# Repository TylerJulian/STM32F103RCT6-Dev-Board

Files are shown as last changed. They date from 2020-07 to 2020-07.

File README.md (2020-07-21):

# STM32F103RCT6 Developement board

A stm32f103RCT6 Breakout board for Sooner Competitive Robotics and Personal use.

Contains PORTs for CAN-Bus protocol and a 6 pin molex power and signal connection.

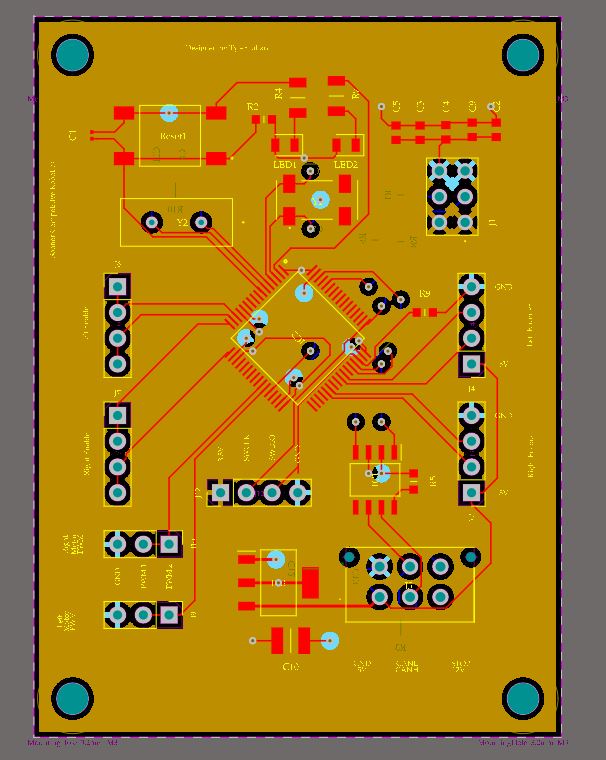
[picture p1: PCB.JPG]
Image of PCB


## Major Components

1x [STM32f103RCT6 microcontroller](https://www.mouser.com/ProductDetail/STMicroelectronics/STM32F103RCT6?qs=%252BB84zevwoRA6TYzZIgOIoA%3D%3D)

1x [SN65HVD230QDR CAN transceiver](https://www.mouser.com/ProductDetail/Texas-Instruments/SN65HVD230QDR?qs=QViXGNcIEAvSeznLG41lqg%3D%3D)

1x [Molex Connector](https://www.molex.com/molex/products/part-detail/pcb_headers/0430450612)

## Minor Components

See bill of materials

## Designers

- Tyler Julian - Designer - [TylerJulian](https://github.com/tylerjulian)

## Built With

- Kicad and Altium- Schematic designed in Kicad then imported to Altium  

## Errata
* tbd

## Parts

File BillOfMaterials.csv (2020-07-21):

Reference | Quantity | Value | Footprint | Datasheet | Description | Height | Manufacturer_Name | Manufacturer_Part_Number | Mouser Part Number | Mouser Price/Stock
C1 | 1 | 1uF | CAPC0603X33N | https://psearch.en.murata.com/capacitor/product/GRM033R61A105ME15%23.html | Capacitor GRM03_0.09 L=0.6mm W=0.3mm T=0.3mm | 0.33 | Murata Electronics | GRM033R61A105ME15J | 81-GRM033R61A105ME5J | https://www.mouser.co.uk/ProductDetail/Murata-Electronics/GRM033R61A105ME15J?qs=5aG0NVq1C4ydTrRWdKcXxA%3D%3D
C10 | 1 | 330uF | CAPC3225X270N | http://psearch.en.murata.com/capacitor/product/GRM32ER71E226KE15%23.pdf | MURATA - GRM32ER60G337ME05K - CAP, MLCC, X5R, 330UF, 4V, 1210 | 2.7 | Murata Electronics | GRM32ER60G337ME05K | 81-GRM32ER60G337ME5K | https://www.mouser.co.uk/ProductDetail/Murata-Electronics/GRM32ER60G337ME05K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
C11 C8 | 2 | 20pf | CAPC0603X33N | https://componentsearchengine.com/Datasheets/1/GRM0335C1H200JA01D.pdf | Multilayer Ceramic Capacitors MLCC - SMD/SMT 0201 20pF 50volts C0G +/-5% | 0.33 | Murata Electronics | GRM0335C1H200JA01D | 81-GRM0335C1H200JA1D | https://www.mouser.com/Search/Refine.aspx?Keyword=81-GRM0335C1H200JA1D
C12 | 1 | 100uF | CAPC3216X180N | https://psearch.en.murata.com/capacitor/product/GRM31CR61A107ME05%23.html | Multilayer Ceramic Capacitors MLCC - SMD/SMT 100UF 10V 20% 1206 | 1.8 | Murata Electronics | GRM31CR61A107ME05L | 81-GRM31CR61A107ME5L | https://www.mouser.co.uk/ProductDetail/Murata-Electronics/GRM31CR61A107ME05L?qs=chTDxNqvsylSo93CzdbYkQ%3D%3D
C2 C3 C4 C5 C13 C9 | 6 | 100nf | CAPC1608X100N | https://psearch.en.murata.com/capacitor/product/GCJ188L8EL104KA07%23.html | Multilayer Ceramic Capacitors MLCC - SMD/SMT | 1 | Murata Electronics | GCJ188L8EL104KA07D | 81-GCJ188L8EL104KA7D | https://www.mouser.co.uk/ProductDetail/Murata-Electronics/GCJ188L8EL104KA07D?qs=rrS6PyfT74fTpbPMbkPm2A%3D%3D
C6 C7 | 2 | 8PF | CAPC0603X33N | https://componentsearchengine.com/Datasheets/1/GRM0335C1E8R0CA01D.pdf | Multilayer Ceramic Capacitors MLCC - SMD/SMT 0201 8.0pF 25volts C0G +/-0.25pF | 0.33 | Murata Electronics | GRM0335C1E8R0CA01D | 81-GRM0335C1E8R0CA1D | https://www.mouser.com/Search/Refine.aspx?Keyword=81-GRM0335C1E8R0CA1D
IC1 | 1 | SN65HVD230QDR | SOIC127P600X175-8N | http://www.ti.com/lit/gpn/SN65HVD230Q | 3.3-V CAN Transceiver with Standby Mode | 1.75 | Texas Instruments | SN65HVD230QDR | 595-SN65HVD230QDR | https://www.mouser.co.uk/ProductDetail/Texas-Instruments/SN65HVD230QDR?qs=QViXGNcIEAvSeznLG41lqg%3D%3D
IC2 | 1 | STM32F103RCT6 | QFP50P1200X1200X160-64N | http://www.st.com/st-web-ui/static/active/en/resource/technical/document/datasheet/CD00191185.pdf | STM32F103RCT6, 32 bit ARM Cortex M3 Microcontroller 72MHz 256 kB Flash, 48 kB RAM, USB CAN I2C 64-Pin LQFP | 1.6 | STMicroelectronics | STM32F103RCT6 | 511-STM32F103RCT6 | https://www.mouser.co.uk/ProductDetail/STMicroelectronics/STM32F103RCT6?qs=%252BB84zevwoRA6TYzZIgOIoA%3D%3D
IC3 | 1 | REG1117-3.3 | SOT230P700X180-4N | http://www.ti.com/lit/ds/symlink/reg1117-33.pdf | 800mA,3.3V,LDO Voltage Reg.,REG1117-3.3 Texas Instruments REG1117-3.3, LDO Voltage Regulator, 0.8A, 3.3 V +/-1%, 3.8 15 Vin, 4-Pin SOT-223 | 1.8 | Texas Instruments | REG1117-3.3 | 595-REG1117-3.3 | https://www.mouser.co.uk/ProductDetail/Texas-Instruments/REG1117-33?qs=sSOk4GDDv7y9bL0tER%2FZXw%3D%3D
J1 | 1 | Boot Pins | TSW-103-XX-YY-D | http://suddendocs.samtec.com/prints/tsw-xxx-xx-xxx-x-xx-xxx-mkt.pdf | 6 Position, Classic PCB Header Strips, 0.100&quot; pitch |  | SAMTEC | TSW-103-07-T-D | 200-TSW10307TD | https://www.mouser.co.uk/ProductDetail/Samtec/TSW-103-07-T-D?qs=hzq9O0YpnZtW9OBlDqG3zw%3D%3D
J10 | 1 | Left Motor PWM | Connector_PinHeader_2.54mm:PinHeader_1x03_P2.54mm_Vertical | ~
J11 | 1 | Power Input | TerminalBlock:TerminalBlock_Altech_AK300-2_P5.00mm | ~
J12 | 1 | SWD | Connector_PinHeader_2.54mm:PinHeader_1x04_P2.54mm_Vertical | ~
J2 | 1 | CAN terminal | TerminalBlock:TerminalBlock_Altech_AK300-2_P5.00mm | ~
J3 | 1 | Righ Encoder | Connector_PinHeader_2.54mm:PinHeader_1x04_P2.54mm_Vertical | ~
J4 | 1 | Left Encoder | Connector_PinHeader_2.54mm:PinHeader_1x04_P2.54mm_Vertical | ~
J5 | 1 | CAN Molex | 430450612 | http://www.molex.com/webdocs/datasheets/pdf/en-us/0430450612_PCB_HEADERS.pdf | 6 way 2 row vertical header,3mm pitch Molex MICRO-FIT 3.0 Series, Series Number 43045, 3mm Pitch 6 Way 2 Row Straight PCB Header, Solder Termination, 5A | 9.91 | Molex | 43045-0612 | 538-43045-0612 | https://www.mouser.co.uk/ProductDetail/Molex/43045-0612?qs=KC2ywxza1kqWo9LLJ5Lh3w%3D%3D
J6 | 1 | Left Enable | Connector_PinHeader_2.54mm:PinHeader_1x04_P2.54mm_Vertical | ~
J7 | 1 | Right Enable | Connector_PinHeader_2.54mm:PinHeader_1x04_P2.54mm_Vertical | ~
J8 J13 | 2 | GPIO Pins | Connector_PinHeader_2.54mm:PinHeader_2x13_P2.54mm_Vertical | ~
J9 | 1 | Right Motor PWM | Connector_PinHeader_2.54mm:PinHeader_1x03_P2.54mm_Vertical | ~
LED1 | 1 | Power Indicator LED | LEDC2012X90N | https://componentsearchengine.com/Datasheets/1/LH R974-LP-1.pdf | Standard LEDs - SMD Hyper Red, 645nm 41mcd, 20mA | 0.9 | OSRAM | LH R974-LP-1 | 720-LHR974-LP-1 | https://www.mouser.co.uk/ProductDetail/OSRAM-Opto-Semiconductors/LH-R974-LP-1?qs=LsPilcdHE7GU7OJxbROzng%3D%3D
LED2 | 1 | LG_R971-KN-1 | LEDC2012X80N |  | Standard LEDs - SMD Green, 570nm 26mcd, 20mA | 0.8 | OSRAM | LG R971-KN-1 | 720-LGR971-KN-1 | https://www.mouser.co.uk/ProductDetail/OSRAM-Opto-Semiconductors/LG-R971-KN-1?qs=LsPilcdHE7EX1EB7GCLHxg%3D%3D
R1 R6 | 2 | 100k | RESC1608X55N |  | Thick Film Resistors - SMD 1/10Watt 100Kohms 1% Commercial Use | 0.55 | Vishay | CRCW0603100KFKEAC | 71-CRCW0603100KFKEAC | https://www.mouser.co.uk/ProductDetail/Vishay-Dale/CRCW0603100KFKEAC?qs=E3Y5ESvWgWPxzfNYyMgX1w%3D%3D
R10 | 1 | 1M | RESC3216X60N | https://componentsearchengine.com/Datasheets/1/CRCW12061M00FKEAC.pdf | Thick Film Resistors - SMD 1/4Watt 1Mohms 1% Commercial Use | 0.6 | Vishay | CRCW12061M00FKEAC | 71-CRCW12061M00FKEAC | https://www.mouser.com/Search/Refine.aspx?Keyword=71-CRCW12061M00FKEAC
R2 R5 R9 R8 | 4 | 10k | RESC1608X55N | https://componentsearchengine.com/Datasheets/1/CRCW060310K0FKEAC.pdf | Thick Film Resistors - SMD 1/10Watt 10Kohms 1% Commercial Use | 0.55 | Vishay | CRCW060310K0FKEAC | 71-CRCW060310K0FKEAC | https://www.mouser.co.uk/ProductDetail/Vishay-Dale/CRCW060310K0FKEAC?qs=E3Y5ESvWgWPkZNxkE0GwZg%3D%3D
R3 | 1 | 120 | RESC3216X60N | http://componentsearchengine.com/Datasheets/1/CRCW1206120RFKEAC.pdf | Thick Film Resistors - SMD 1/4Watt 120ohms 1% Commercial Use | 0.6 | Vishay | CRCW1206120RFKEAC | 71-CRCW1206120RFKEAC | https://www.mouser.co.uk/ProductDetail/Vishay-Dale/CRCW1206120RFKEAC?qs=E3Y5ESvWgWNzKkdgimZfBg%3D%3D
R4 R7 | 2 | 510 | RESC3216X60N | https://componentsearchengine.com/Datasheets/1/CRCW1206510RFKEAC.pdf | Thick Film Resistors - SMD 1/4Watt 510ohms 1% Commercial Use | 0.6 | Vishay | CRCW1206510RFKEAC | 71-CRCW1206510RFKEAC | https://www.mouser.com/Search/Refine.aspx?Keyword=71-CRCW1206510RFKEAC
Reset1 | 1 | Reset | LL3301NF065QG | http://spec_sheets.e-switch.com/specs/P090002.pdf | E-SWITCH - LL3301NF065QG - TACTILE SW, SPST, 0.05A, 12VDC, SOLDER | 4 | E-Switch | LL3301NF065QG | 612-LL3301NF065QG | https://www.mouser.co.uk/ProductDetail/E-Switch/LL3301NF065QG?qs=QtyuwXswaQiWhwgY68YTTw%3D%3D
Y1 | 1 | 32.768KHZ | ABS2532000KHZT | https://abracon.com/Resonators/abs25.pdf | Abracon 32.768kHz Crystal Unit +/-10ppm SMD 4-Pin 8 x 3.8 x 2.5mm | 2.5 | ABRACON | ABS25-32.768KHZ-6-1-T | 815-ABS25-32.7-6-1-T | https://www.mouser.co.uk/ProductDetail/ABRACON/ABS25-32768KHZ-6-1-T?qs=3LVMET7lfiORXXovA%252BX5Lg%3D%3D
Y2 | 1 | 8Mhz | LFXTAL057135Bulk | https://componentsearchengine.com/Datasheets/1/LFXTAL057135Bulk.pdf | Crystals 8MHz 16pF -40C 85C | 4.1 | IQD | LFXTAL057135Bulk | 449-LFXTAL057135BULK | https://www.mouser.com/Search/Refine.aspx?Keyword=449-LFXTAL057135BULK

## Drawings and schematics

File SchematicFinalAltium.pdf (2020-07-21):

# VCC 1 2

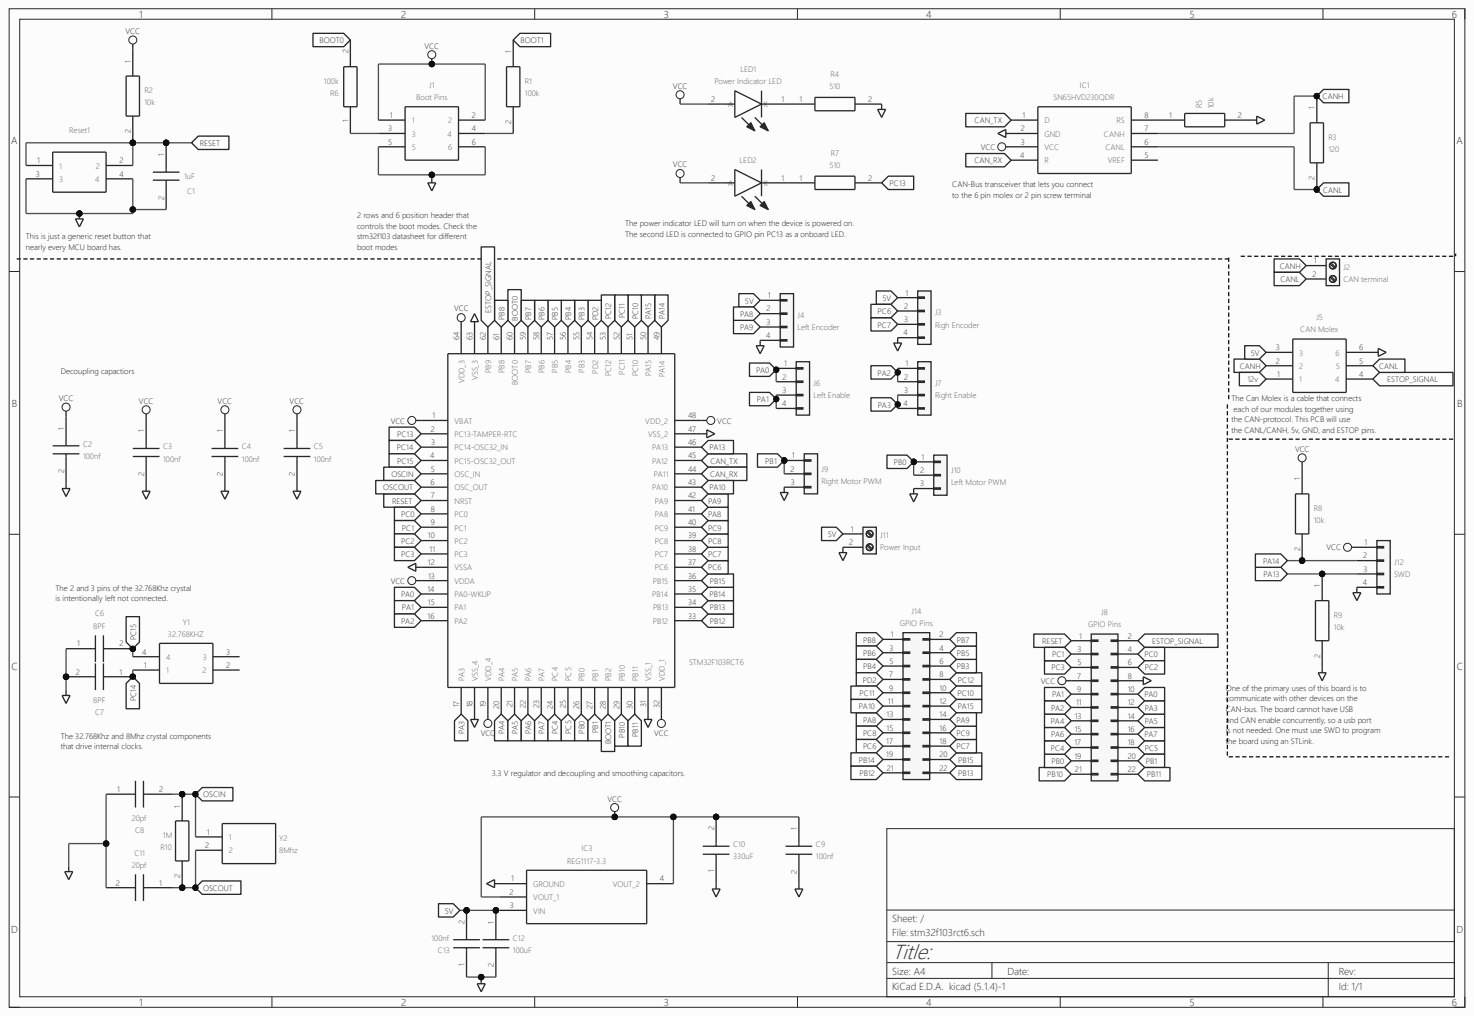
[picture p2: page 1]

CAN-Bus transceiver that lets you connect
to the 6 pin molex or 2 pin screw terminal

2 rows and 6 position header that
controls the boot modes. Check the
stm32f103 datasheet for different
boot modes

The power indicator LED will turn on when the device is powered on.
The second LED is connected to GPIO pin PC13 as a onboard LED.

This is just a generic reset button that
nearly every MCU board has.

CANH
The Can Molex is a cable that connects
each of our modules together using
the CAN-protocol. This PCB will use
the CANL/CANH, 5v, GND, and ESTOP pins.

The 2 and 3 pins of the 32.768Khz crystal
is intentionally left not connected.

One of the primary uses of this board is to
communicate with other devices on the
CAN-bus. The board cannot have USB
and CAN enable concurrently, so a usb port
is not needed. One must use SWD to program
the board using an STLink.

The 32.768Khz and 8Mhz crystal components
that drive internal clocks.

3.3 V regulator and decoupling and smoothing capacitors.

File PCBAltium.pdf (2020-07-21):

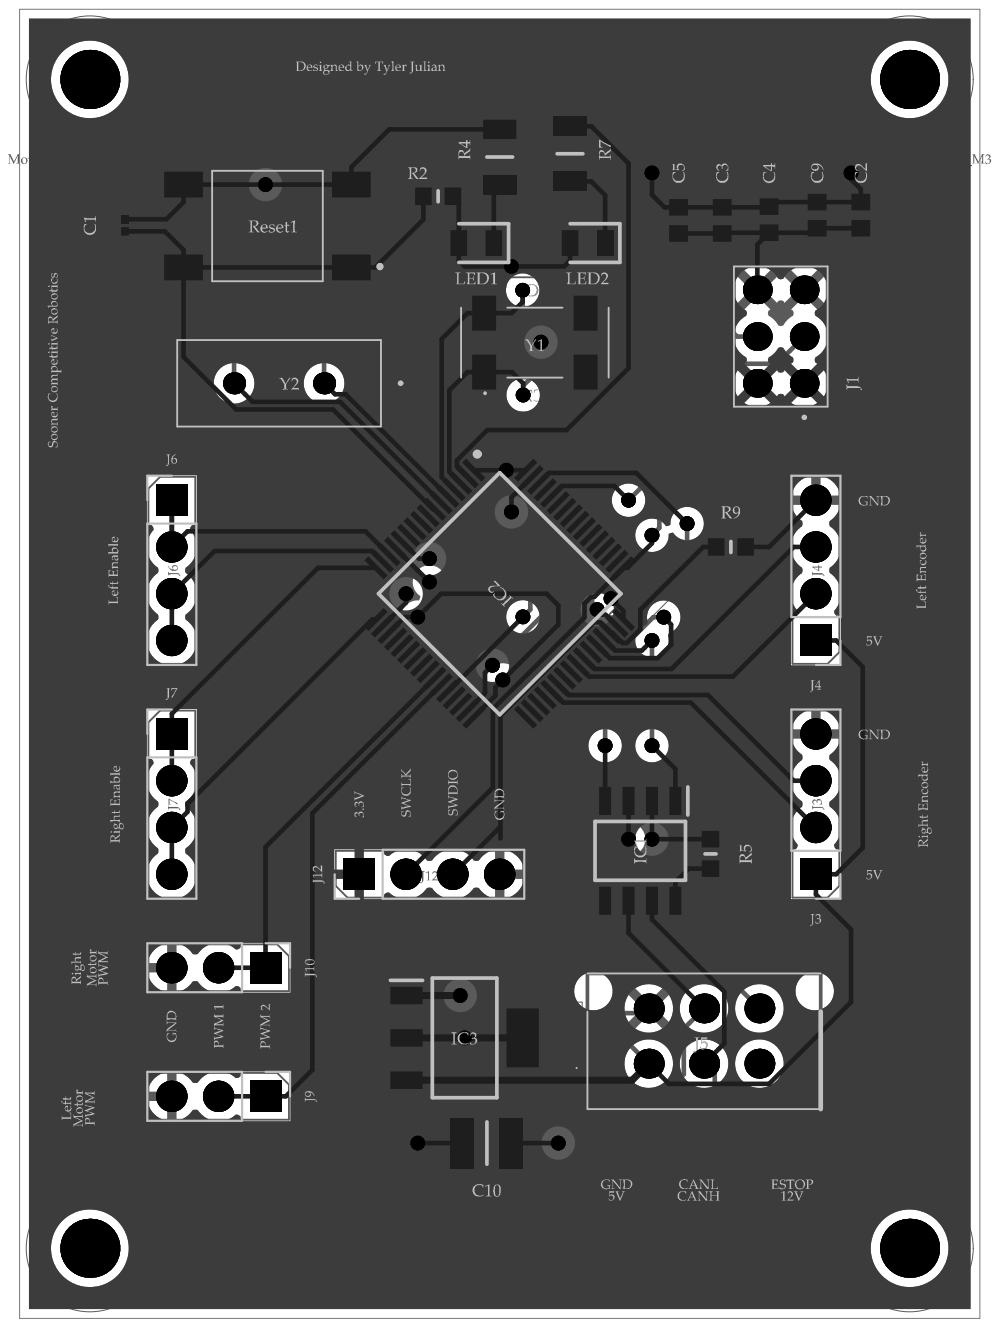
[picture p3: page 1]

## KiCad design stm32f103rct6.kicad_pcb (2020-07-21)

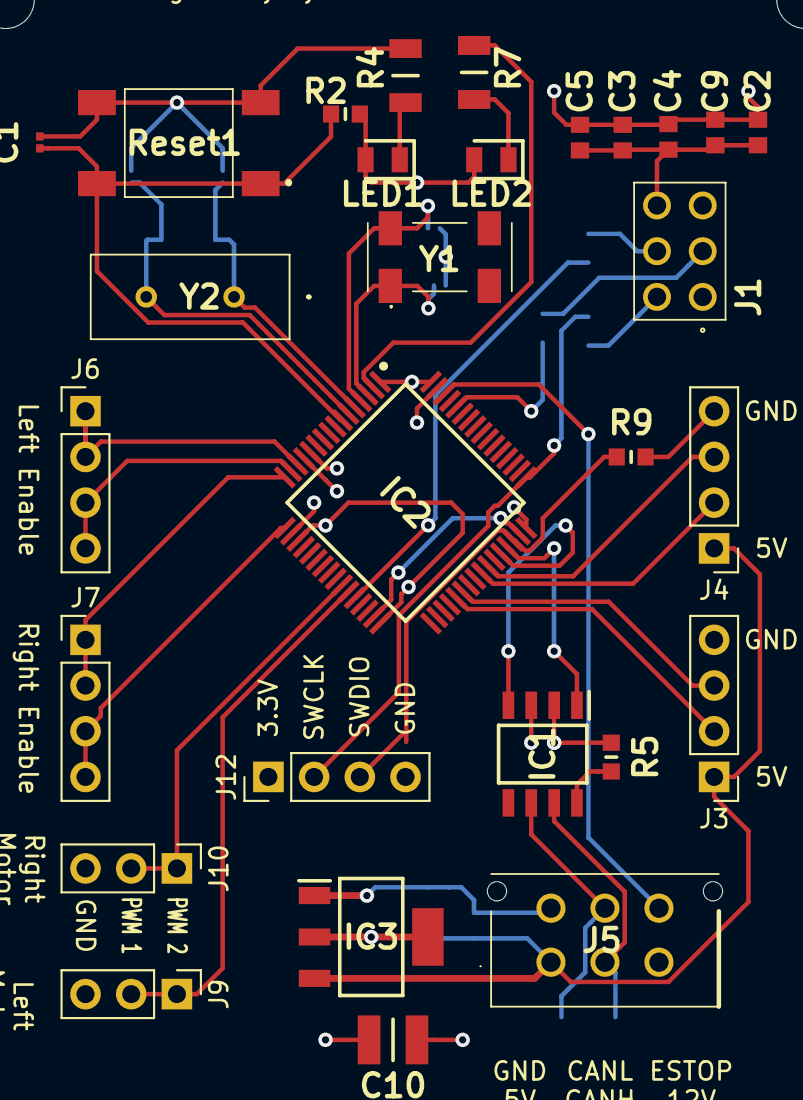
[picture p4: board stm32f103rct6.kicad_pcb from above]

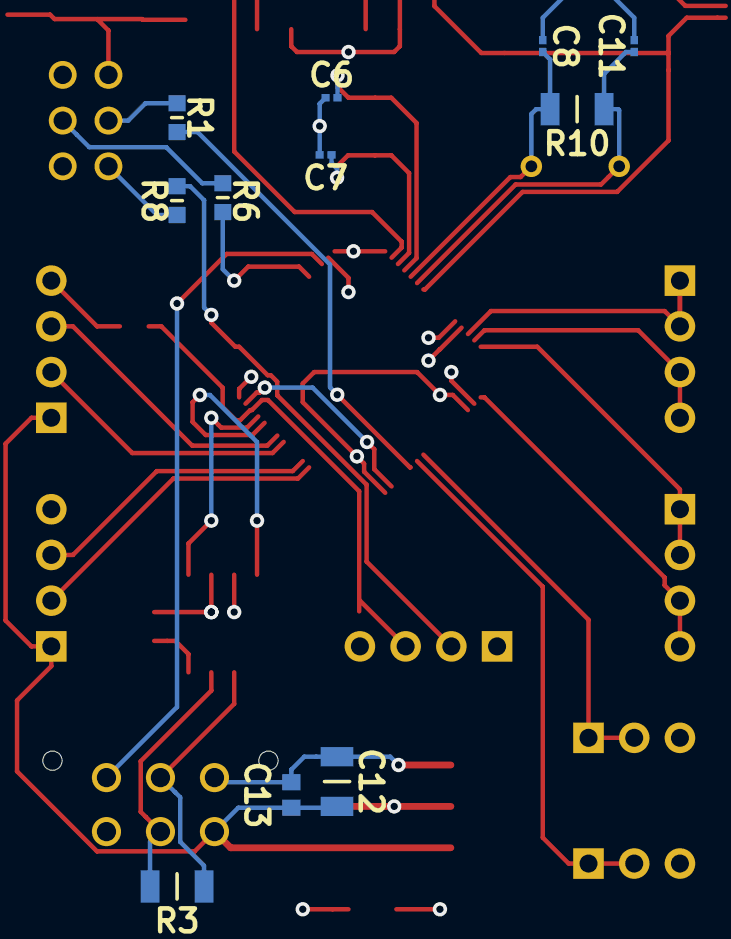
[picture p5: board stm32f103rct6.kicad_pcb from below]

Board: 4 copper layers, 40 parts (11 on the bottom side), 33 nets.

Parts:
C1: 1uF; CAPC0603X33N
C2, C3, C4, C5, C9, C13: 100nf; CAPC1608X100N
C6, C7: 8PF; CAPC0603X33N
C8, C11: 20pf; CAPC0603X33N
C10: 330uF; CAPC3225X270N
C12: 100uF; CAPC3216X180N
IC1: SN65HVD230QDR; SOIC127P600X175-8N
IC2: STM32F103RCT6; QFP50P1200X1200X160-64N
IC3: REG1117-3.3; SOT230P700X180-4N
J1: Boot Pins; TSW-103-XX-YY-D
J3: Righ Encoder; PinHeader_1x04_P2.54mm_Vertical
J4: Left Encoder; PinHeader_1x04_P2.54mm_Vertical
J5: CAN Molex; 430450612
J6: Left Enable; PinHeader_1x04_P2.54mm_Vertical
J7: Right Enable; PinHeader_1x04_P2.54mm_Vertical
J9: Right Motor PWM; PinHeader_1x03_P2.54mm_Vertical
J10: Left Motor PWM; PinHeader_1x03_P2.54mm_Vertical
J12: SWD; PinHeader_1x04_P2.54mm_Vertical
LED1: Power Indicator LED; LEDC2012X90N
LED2: LG_R971-KN-1; LEDC2012X80N
R1, R6: 100k; RESC1608X55N
R2, R5, R8, R9: 10k; RESC1608X55N
R3: 120; RESC3216X60N
R4, R7: 510; RESC3216X60N
R10: 1M; RESC3216X60N
Reset1: Reset; LL3301NF065QG
Y1: 32.768KHZ; ABS2532000KHZT
Y2: 8Mhz; LFXTAL057135Bulk

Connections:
5V: C12.1, C13.2, IC3.3, J3.1, J4.1, J5.3
BOOT0: IC2.60, R6.2
BOOT1: IC2.28, R1.1
CANH: IC1.7, J5.2, R3.1
CANL: IC1.6, J5.5, R3.2
CAN_RX: IC1.4, IC2.44
CAN_TX: IC1.1, IC2.45
ESTOP_SIGNAL: IC2.62, J5.4
GND: C1.2, C2.2, C3.2, C4.2, C5.2, C6.1, C7.2, C8.1, C9.2, C10.1, C11.2, C12.2, C13.1, IC1.2, IC2.12, IC2.18, IC2.31, IC2.47, IC2.63, IC3.1, J1.5, J1.6, J3.4, J4.4, J5.6, J9.3, J10.3, J12.4, R4.2, R5.2, R9.2, Reset1.3, Reset1.4
unnamed: IC1.8, R5.1
unnamed: J1.3, R6.1
unnamed: J1.4, R1.2
unnamed: LED1.1, R4.1
unnamed: LED2.1, R7.1
OSCIN: C8.2, IC2.5, R10.1, Y2.1
OSCOUT: C11.1, IC2.6, R10.2, Y2.2
PA0: IC2.14, J6.1, J6.2
PA1: IC2.15, J6.3, J6.4
PA2: IC2.16, J7.1, J7.2
PA3: IC2.17, J7.3, J7.4
PA8: IC2.41, J4.2
PA9: IC2.42, J4.3
PA13: IC2.46, J12.3, R9.1
PA14: IC2.49, J12.2, R8.2
PB0: IC2.26, J10.1, J10.2
PB1: IC2.27, J9.1, J9.2
PC6: IC2.37, J3.2
PC7: IC2.38, J3.3
PC13: IC2.2, R7.2
PC14: C7.1, IC2.3, Y1.1
PC15: C6.2, IC2.4, Y1.4
RESET: C1.1, IC2.7, R2.2, Reset1.1, Reset1.2
VCC: C2.1, C3.1, C4.1, C5.1, C9.1, C10.2, IC1.3, IC2.1, IC2.13, IC2.19, IC2.32, IC2.48, IC2.64, IC3.2, IC3.4, J1.1, J1.2, J12.1, LED1.2, LED2.2, R2.1, R8.1

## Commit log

2020-07-13 Initial version 1 of the dev board.
    Might need to reorganize the pinout headers.
    [stm32f103rct6.kicad_pcb, stm32f103rct6.sch]
2020-07-13 Annotate V1 of schematic
2020-07-14 Version 2 of the schematic
    Added JST connections for Enable, PWM, and Power
    [stm32f103rct6.sch]
2020-07-21 Add files via upload
    Upload altium Schematic
2020-07-21 New pcb schematic
2020-07-21 Add Bill of Materials
    [BillOfMaterials.csv]
2020-07-21 add PCB screenshot
2020-07-21 Version of the board that I ordered
    [stm32f103rct6.kicad_pcb, stm32f103rct6.sch]
2020-07-29 upload soldered board
